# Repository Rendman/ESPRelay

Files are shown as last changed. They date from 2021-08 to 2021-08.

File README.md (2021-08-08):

# ESP8266 2-Channel Relay
---
This project was originally designed to act a as wifi enabled IoT garage door opener. It has two relay channels and two sensor channels. 

This hardware is largely a rip off of standard "Arduino" modules that you can find on eBay and other sources. It's really nothing special. It does proivde a higher degree of integration as you can mount a NodeMCU directly to the PCB. 

I've tested this with the TASMOTA software and it seems to work pretty well. 

Here is the TASMOTA Config for the module. Any kind of Commands or Backlog things are left to the user.

GPIO -> Function
---
GPIO4 -> Relay2  
GPIO5 -> Relay1  
GPIO12 -> Switch2  
GPIO14 -> Switch1  

This project also includes FreeCAD files for a 3D printable box for the device. I used the following as the magnetic sensor, but any other one would work just fine:

[Seco-Larm Overhead Door Sensor](https://www.amazon.com/SECO-LARM-SM-4201-LQ-TRACK-MOUNT-OVERHEAD/dp/B011OXPZ7Y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)

Here are a few pictures of the device and the sensor

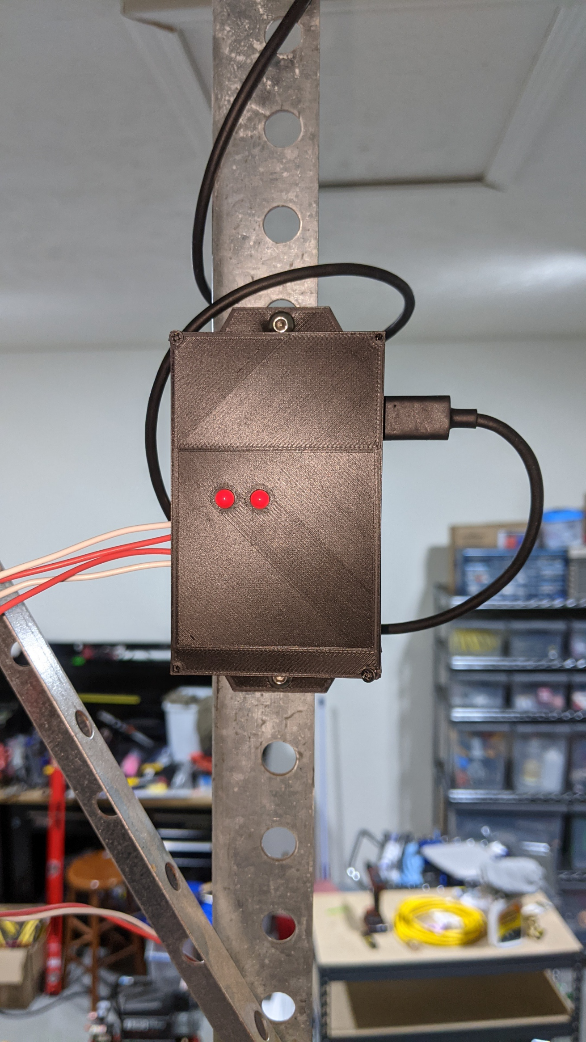
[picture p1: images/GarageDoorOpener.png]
Device Picture

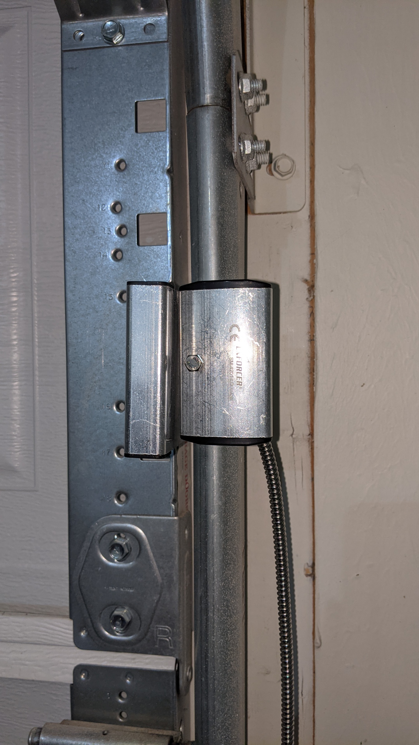
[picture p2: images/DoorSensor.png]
Sensor Picture


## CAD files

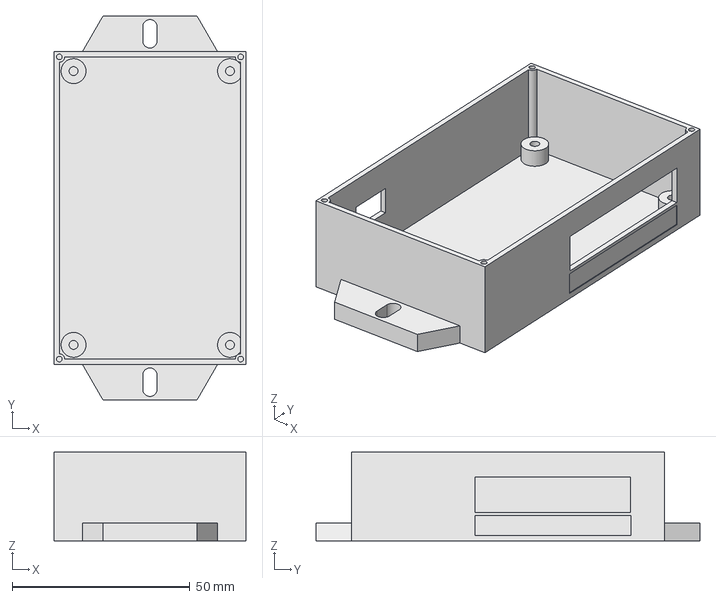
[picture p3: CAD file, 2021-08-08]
ESPRelay_case.FCStd
54.0 x 108.0 x 25.0 mm

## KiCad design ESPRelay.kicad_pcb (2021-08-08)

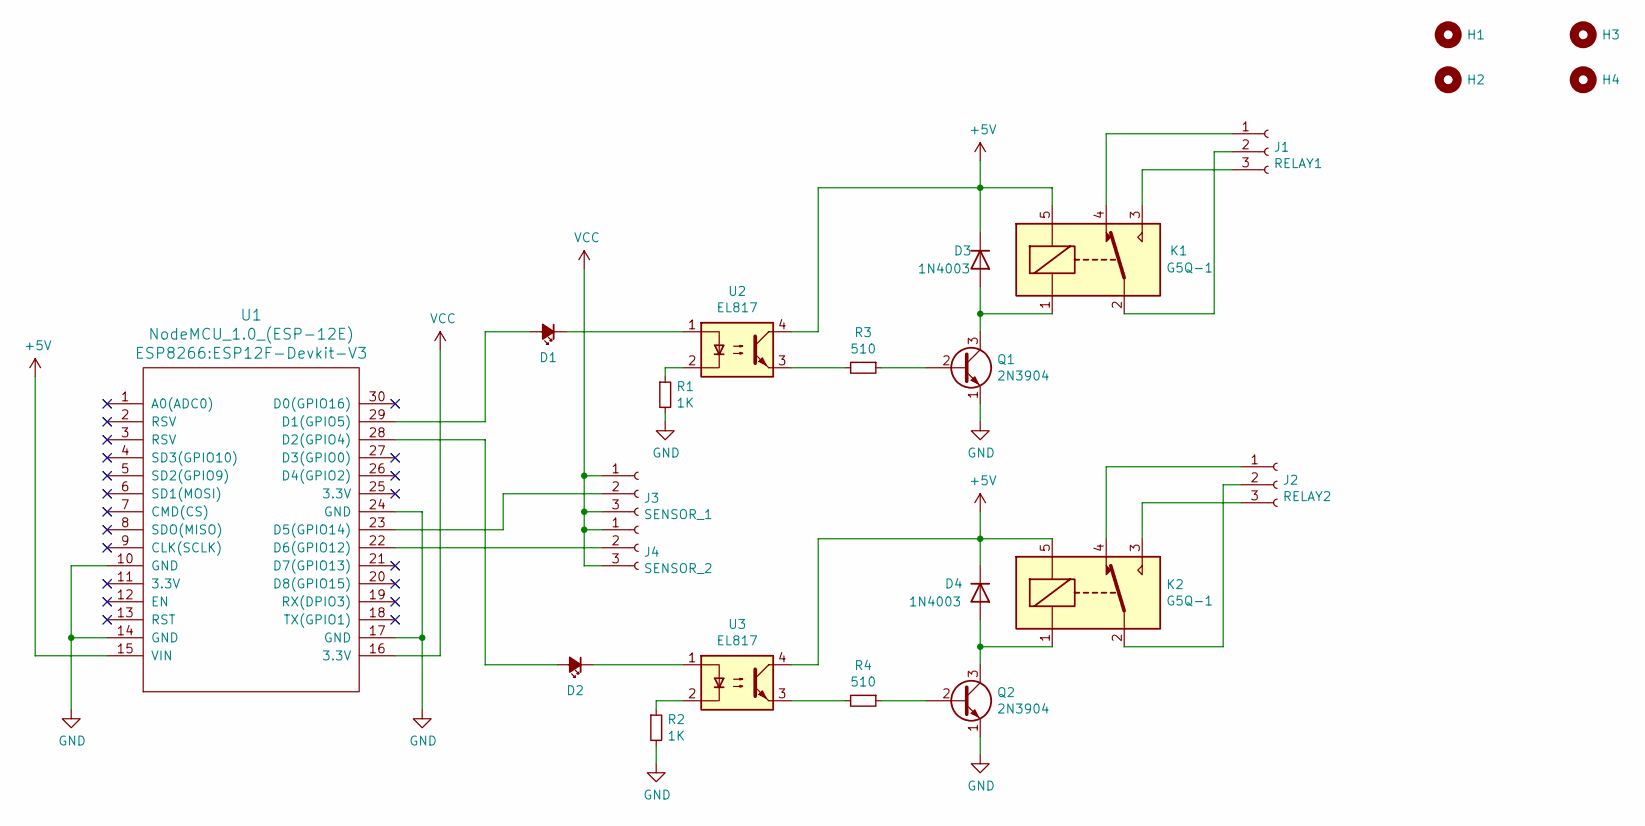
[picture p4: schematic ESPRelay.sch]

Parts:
D1, D2: LED_Small_ALT; LED_D5.0mm
D3, D4: 1N4003; D_DO-41_SOD81_P10.16mm_Horizontal
H1, H2, H3, H4: MountingHole; MountingHole_3.2mm_M3
J1: RELAY1; 5442251
J2: RELAY2; 5442251
J3: SENSOR_1; TerminalBlock_TE_282834-3_1x03_P2.54mm_Horizontal
J4: SENSOR_2; TerminalBlock_TE_282834-3_1x03_P2.54mm_Horizontal
K1, K2: G5Q-1; Relay_SPDT_Omron-G5Q-1
Q1, Q2: 2N3904; TO-92_Inline
R1, R2: 1K; R_Axial_DIN0204_L3.6mm_D1.6mm_P5.08mm_Horizontal
R3, R4: 510; R_Axial_DIN0204_L3.6mm_D1.6mm_P5.08mm_Horizontal
U1: NodeMCU_1.0_(ESP-12E); ESP12F-Devkit-V3
U2, U3: EL817; DIP-4_W7.62mm

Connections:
+5V: D3.1 (K), D4.1 (K), K1.5, K2.5, U1.15 (VIN), U2.4, U3.4
GND: Q1.1 (E), Q2.1 (E), R1.2, R2.2, U1.10 (GND), U1.14 (GND), U1.17 (GND), U1.24 (GND)
unnamed: D1.1 (K), U2.1
unnamed: D1.2 (A), U1.29 (D1(GPIO5))
unnamed: D2.1 (K), U3.1
unnamed: D2.2 (A), U1.28 (D2(GPIO4))
unnamed: D3.2 (A), K1.1, Q1.3 (C)
unnamed: D4.2 (A), K2.1, Q2.3 (C)
unnamed: J1.1, K1.4
unnamed: J1.2, K1.2
unnamed: J1.3, K1.3
unnamed: J2.1, K2.4
unnamed: J2.2, K2.2
unnamed: J2.3, K2.3
unnamed: J3.2, U1.23 (D5(GPIO14))
unnamed: J4.2, U1.22 (D6(GPIO12))
unnamed: Q1.2 (B), R3.1
unnamed: Q2.2 (B), R4.1
unnamed: R1.1, U2.2
unnamed: R2.1, U3.2
unnamed: R3.2, U2.3
unnamed: R4.2, U3.3
VCC: J3.1, J3.3, J4.1, J4.3, U1.16 (3.3V)

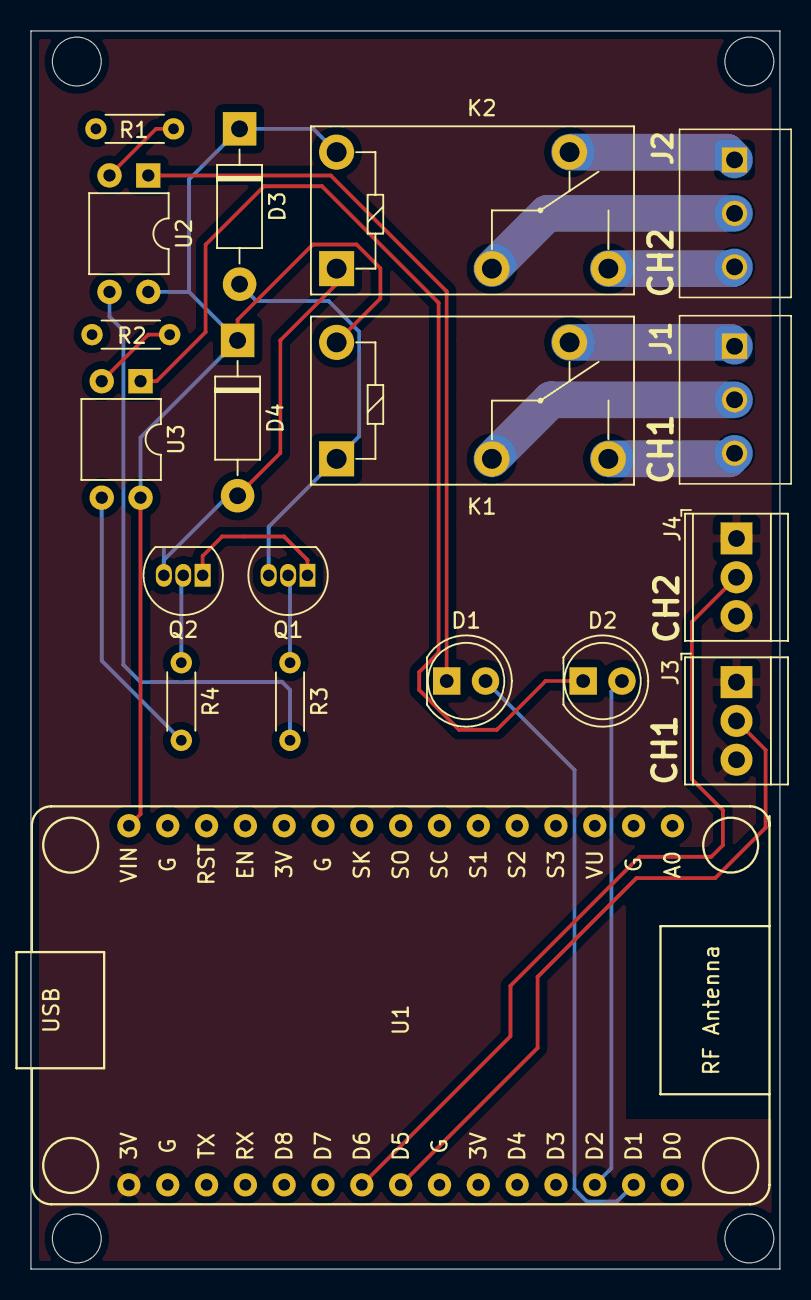
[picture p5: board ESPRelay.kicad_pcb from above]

Board: 2 copper layers, 49.0 x 81.0 mm, 23 parts (0 on the bottom side), 23 nets.

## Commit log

2021-02-06 Initial Commit of Finished files
    [Case Body.stl, Case Cover.stl, ESPRelay.kicad_pcb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]
2021-02-07 Removed offensive message on silkscreen
    [ESPRelay.kicad_pcb]
2021-02-13 Slight cosmetic tweaks to manufacturing data and PCB silkscreen
    [ESPRelay.kicad_pcb]
2021-02-28 Fixed misconnected sensor inputs
    [Case Body.stl, ESPRelay.kicad_pcb, ESPRelay.sch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]
2021-08-08 Fix error with relay connections to NodeMCU. Include README.md and git ignore file.
    [ESPRelay-B_Cu.gbr, ESPRelay-B_Mask.gbr, ESPRelay-B_Paste.gbr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]
2021-08-08 Removed generated files
    [Case Body.stl, Case Cover.stl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]
